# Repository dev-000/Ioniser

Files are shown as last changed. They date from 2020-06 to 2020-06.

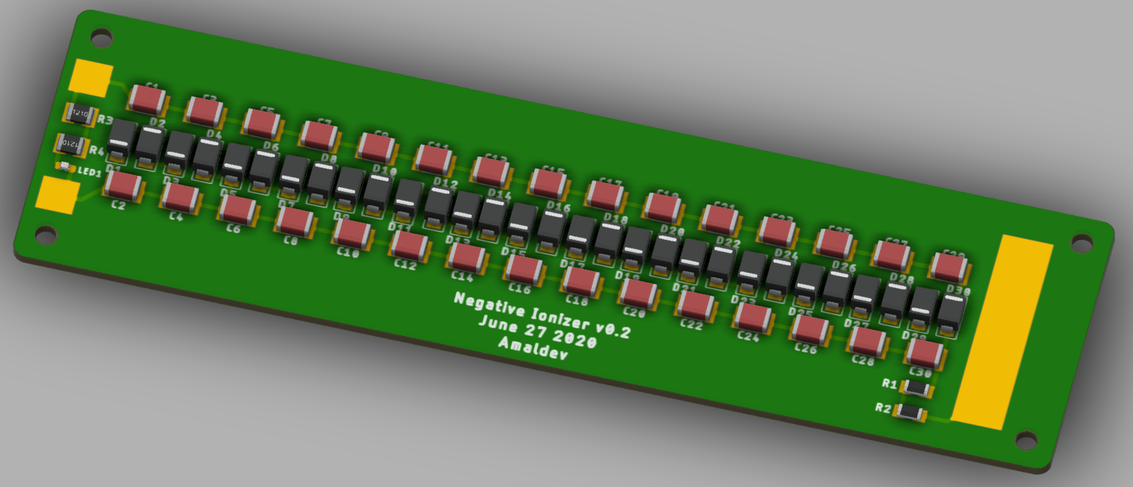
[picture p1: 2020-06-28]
Negative Ioniser/Negative_Ioniser_PCB_3D.png

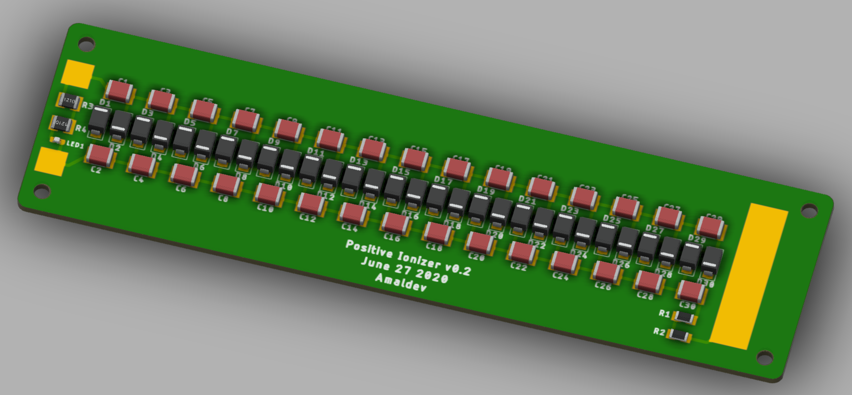
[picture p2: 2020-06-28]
Positive Ioniser/Positive_Ioniser_PCB_3D.png

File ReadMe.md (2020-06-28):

# Build an Ioniser in under $10

This repo contains all the hardware files needed to build a low cost ioniser. It helps in settling dust particles around the device, effectively "cleansing" the air in the room.  Repo also contains the simulation files if you want to check the theoretical output voltages.

Details and circuit explanations are mentioned in the link below. Please do read the links fully before starting the build process. 
 - [http://amaldev.blog/build-ioniser-in-under-10-dollars/](http://amaldev.blog/build-ioniser-in-under-10-dollars/)
 - [http://amaldev.blog/build-an-ioniser-in-under-10-dollars-part-2/](http://amaldev.blog/build-an-ioniser-in-under-10-dollars-part-2/)

Repo contains files for both Positive and Negative Ioniser which gives you a High Voltage positive and negative DC voltages. The circuits are very similar except that the diodes are swapped. Bill of Materials remains same for both versions. 

You can upload the *Gerbers.zip* file directly on to any online PCB manufacturing shop to get it made or edit the Eagle schematic and layout files to your liking.   

Please be very careful dealing with AC voltages and High voltage DC outputs. Capacitors do retain charge for sometime and you will get a zap if you touch them. 

**License:** Released as open source hardware. Do whatever you want with it. :smiley:

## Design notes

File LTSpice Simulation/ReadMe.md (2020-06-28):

# LTSpice Simulation
- Download LTSpice from Analog Device's [Website](https://www.analog.com/en/design-center/design-tools-and-calculators/ltspice-simulator.html).
- Open the *Ioniser_LTspice.asc* file in LTspice 
- In the menu goto *Simulate --> Run*
- Wait a few minutes for simulation to complete. 
- Click and put the voltage probes on the nodes *Input_AC*, *Positive_Output*, *Negative_Output* to see the waveforms.

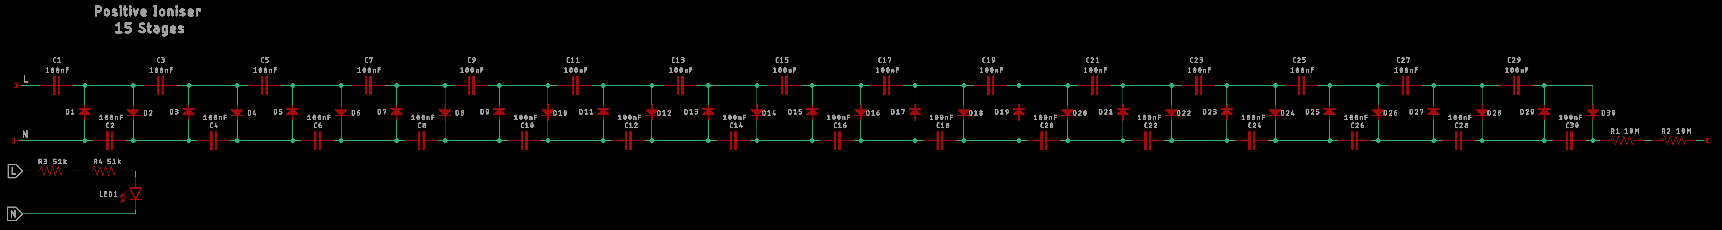
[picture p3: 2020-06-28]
Positive Ioniser/Positive_Ioniser_Schematic.png

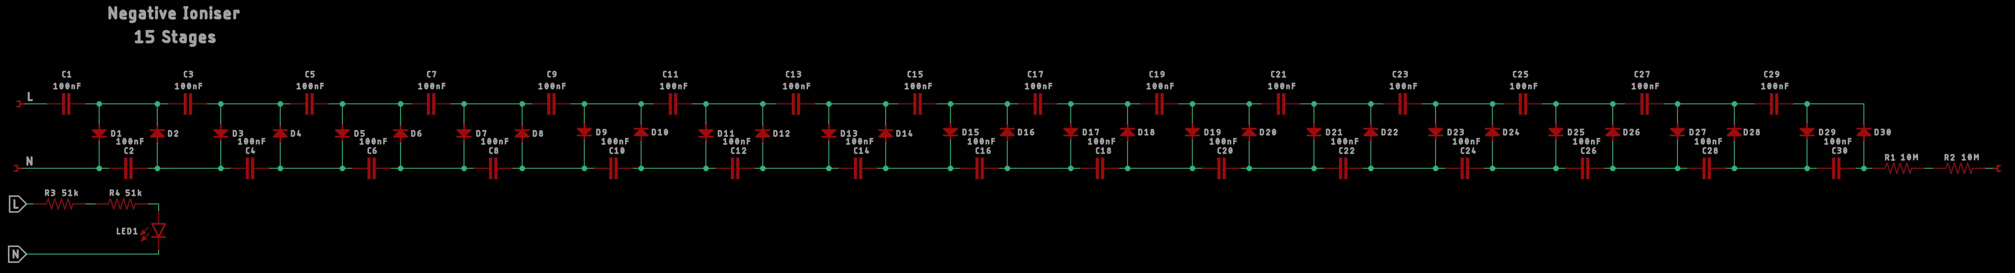
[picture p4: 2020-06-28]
Negative Ioniser/Negative_Ioniser_Schematic.png

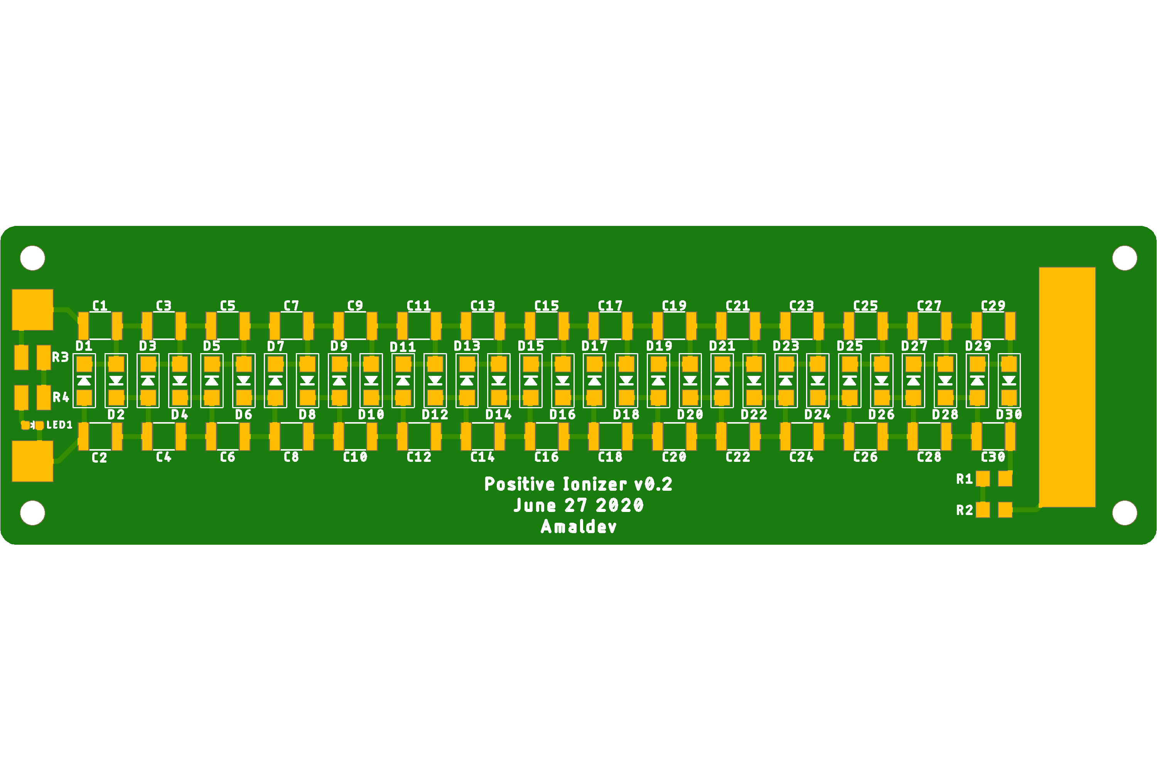
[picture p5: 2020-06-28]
Positive Ioniser/Positive_Ioniser_PCB_Layout.png

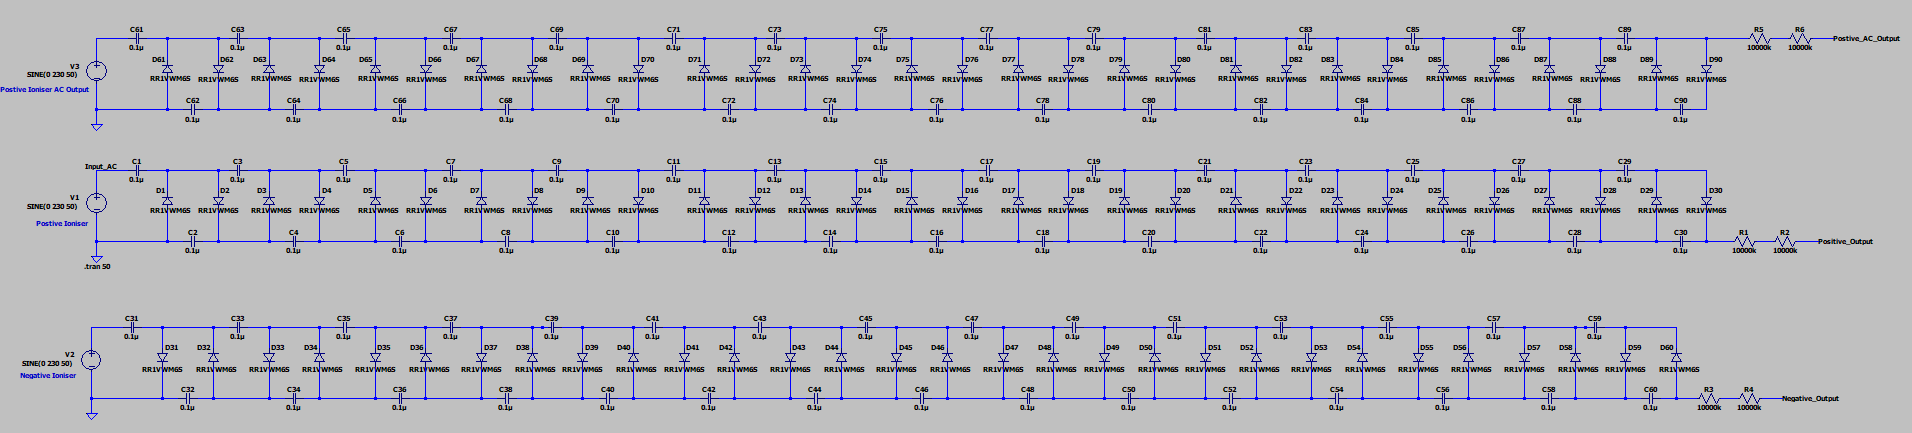
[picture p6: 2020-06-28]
LTSpice Simulation/Simulation Circuit.png

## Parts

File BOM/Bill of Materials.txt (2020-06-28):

Qty Value           Device          Package            Parts                                                                                                                                       Description I-RATING PART-NUM         RATED TOLERANCE V-RATING
30  100nF           CAPACITOR-1812  C1812              C1, C2, C3, C4, C5, C6, C7, C8, C9, C10, C11, C12, C13, C14, C15, C16, C17, C18, C19, C20, C21, C22, C23, C24, C25, C26, C27, C28, C29, C30                      1812B104K631CT   630V  ±10%              
2   10M             RESISTOR-1206   R1206              R1, R2                                                                                                                                                           1206W4F1005T5E   0.25W ±1%               
2   51k             RESISTOR-1210   R1210              R3, R4                                                                                                                                                           CR1210J51K0P05Z  0.5W  ±5%               
30  DIODE-1N4007    DIODE-1N4007    DO-214A            D1, D2, D3, D4, D5, D6, D7, D8, D9, D10, D11, D12, D13, D14, D15, D16, D17, D18, D19, D20, D21, D22, D23, D24, D25, D26, D27, D28, D29, D30             1A       1N4007G                          1kV     
1   LED-0603-SMD    LED-0603-SMD    LED-0603           LED1                                                                                                                                                             D-060306R1/SS2/L                         

Other Mechanical Parts:

1 unit:  3mm Acrylic Cover (Laser Cut) - FileName for laser cutting Acrylic-Cover-Laser-Cut.dxf              
4 units: 20mm(long) spacer/Standoff - Nylon Screws (LCSC Part Number: C242804)
4 units: M3 x 5mm(long) - Nylon Screws (LCSC Part Number: C194616)

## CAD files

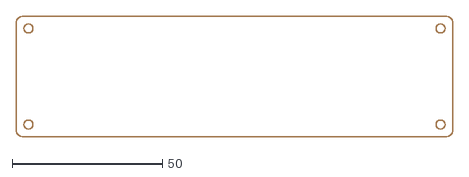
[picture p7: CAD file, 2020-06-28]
BOM/Acrylic-Cover-Laser-Cut.dxf
145.0 x 40.0

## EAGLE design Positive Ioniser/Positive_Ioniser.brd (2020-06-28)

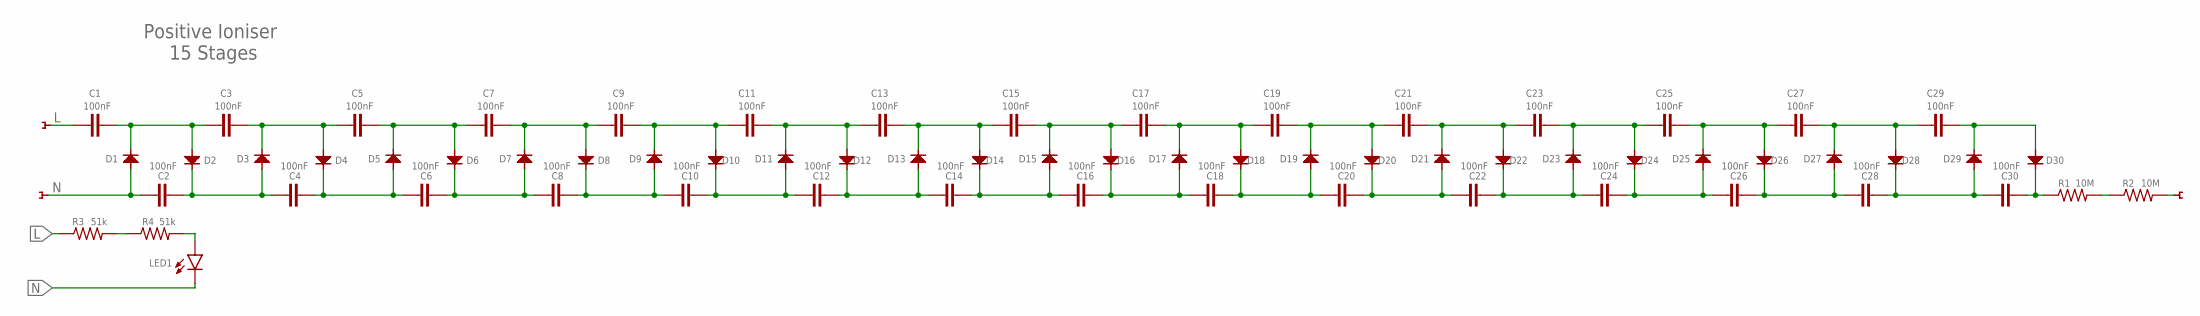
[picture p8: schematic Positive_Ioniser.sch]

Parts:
C1, C2, C3, C4, C5, C6, C7, C8, C9, C10, C11, C12, C13, C14, C15, C16, C17, C18, C19, C20, C21, C22, C23, C24, C25, C26, C27, C28, C29, C30: 100nF; C1812; TOLERANCE ±10%; PART-NUM 1812B104K631CT
D1, D2, D3, D4, D5, D6, D7, D8, D9, D10, D11, D12, D13, D14, D15, D16, D17, D18, D19, D20, D21, D22, D23, D24, D25, D26, D27, D28, D29, D30: DIODE-1N4007; DO-214A; PART-NUM 1N4007G
LED1: LED-0603-SMD; LED-0603; PART-NUM D-060306R1/SS2/L
R1, R2: 10M; R1206; TOLERANCE ±1%; PART-NUM 1206W4F1005T5E
R3, R4: 51k; R1210; TOLERANCE ±5%; PART-NUM CR1210J51K0P05Z
TP1, TP2: TEST-POINT5MM; SMD-SQ-PADS-5MM
TP3: TEST-POINT30X10; LONG-RECT-PAD-50MM

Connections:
L: C1.1, R3.1, TP1.P$1
N: C2.1, D1.ANODE (A), LED1.C, TP2.P$1
unnamed: C2.2, C4.1, D2.CATHODE (C), D3.ANODE (A)
unnamed: C1.2, C3.1, D1.CATHODE (C), D2.ANODE (A)
unnamed: R3.2, R4.1
unnamed: R1.2, R2.1
unnamed: C5.2, C7.1, D5.CATHODE (C), D6.ANODE (A)
unnamed: C4.2, C6.1, D4.CATHODE (C), D5.ANODE (A)
unnamed: LED1.A, R4.2
unnamed: C6.2, C8.1, D6.CATHODE (C), D7.ANODE (A)
unnamed: C3.2, C5.1, D3.CATHODE (C), D4.ANODE (A)
unnamed: C9.2, C11.1, D9.CATHODE (C), D10.ANODE (A)
unnamed: C8.2, C10.1, D8.CATHODE (C), D9.ANODE (A)
unnamed: C10.2, C12.1, D10.CATHODE (C), D11.ANODE (A)
unnamed: C7.2, C9.1, D7.CATHODE (C), D8.ANODE (A)
unnamed: C13.2, C15.1, D13.CATHODE (C), D14.ANODE (A)
unnamed: C12.2, C14.1, D12.CATHODE (C), D13.ANODE (A)
unnamed: C14.2, C16.1, D14.CATHODE (C), D15.ANODE (A)
unnamed: C11.2, C13.1, D11.CATHODE (C), D12.ANODE (A)
unnamed: C17.2, C19.1, D17.CATHODE (C), D18.ANODE (A)
unnamed: C16.2, C18.1, D16.CATHODE (C), D17.ANODE (A)
unnamed: C18.2, C20.1, D18.CATHODE (C), D19.ANODE (A)
unnamed: C15.2, C17.1, D15.CATHODE (C), D16.ANODE (A)
unnamed: C21.2, C23.1, D21.CATHODE (C), D22.ANODE (A)
unnamed: C20.2, C22.1, D20.CATHODE (C), D21.ANODE (A)
unnamed: C22.2, C24.1, D22.CATHODE (C), D23.ANODE (A)
unnamed: C19.2, C21.1, D19.CATHODE (C), D20.ANODE (A)
unnamed: C25.2, C27.1, D25.CATHODE (C), D26.ANODE (A)
unnamed: C24.2, C26.1, D24.CATHODE (C), D25.ANODE (A)
unnamed: C26.2, C28.1, D26.CATHODE (C), D27.ANODE (A)
unnamed: C23.2, C25.1, D23.CATHODE (C), D24.ANODE (A)
unnamed: C27.2, C29.1, D27.CATHODE (C), D28.ANODE (A)
unnamed: C28.2, C30.1, D28.CATHODE (C), D29.ANODE (A)
unnamed: C29.2, D29.CATHODE (C), D30.ANODE (A)
unnamed: C30.2, D30.CATHODE (C), R1.1
OUTPUT: R2.2, TP3.1

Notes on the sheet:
15 Stages
Positive Ioniser

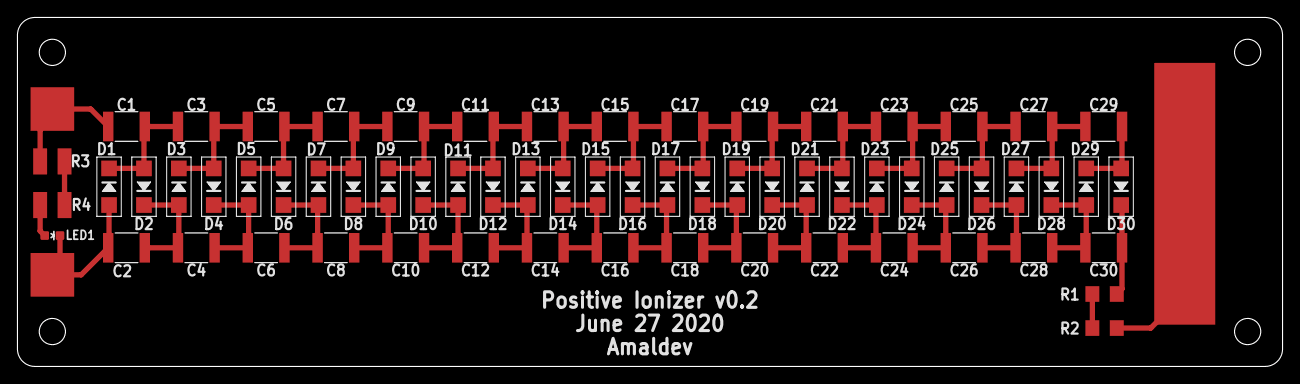
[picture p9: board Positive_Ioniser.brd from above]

Board: 2 copper layers, 145.0 x 40.0 mm, 68 parts (0 on the bottom side), 36 nets.
